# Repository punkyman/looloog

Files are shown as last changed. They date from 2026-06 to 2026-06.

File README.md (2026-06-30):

# looloog

The looloog is a DIY midi instrument intended to make custom inputs for [vcvrack](https://vcvrack.com/)

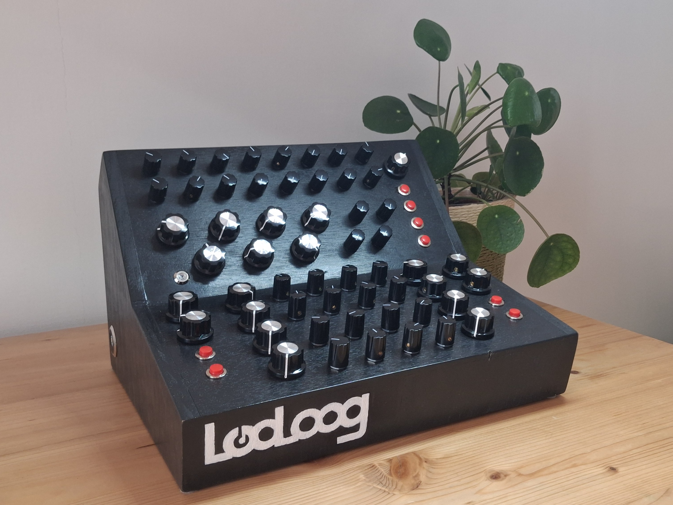
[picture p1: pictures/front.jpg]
Front of the looloog


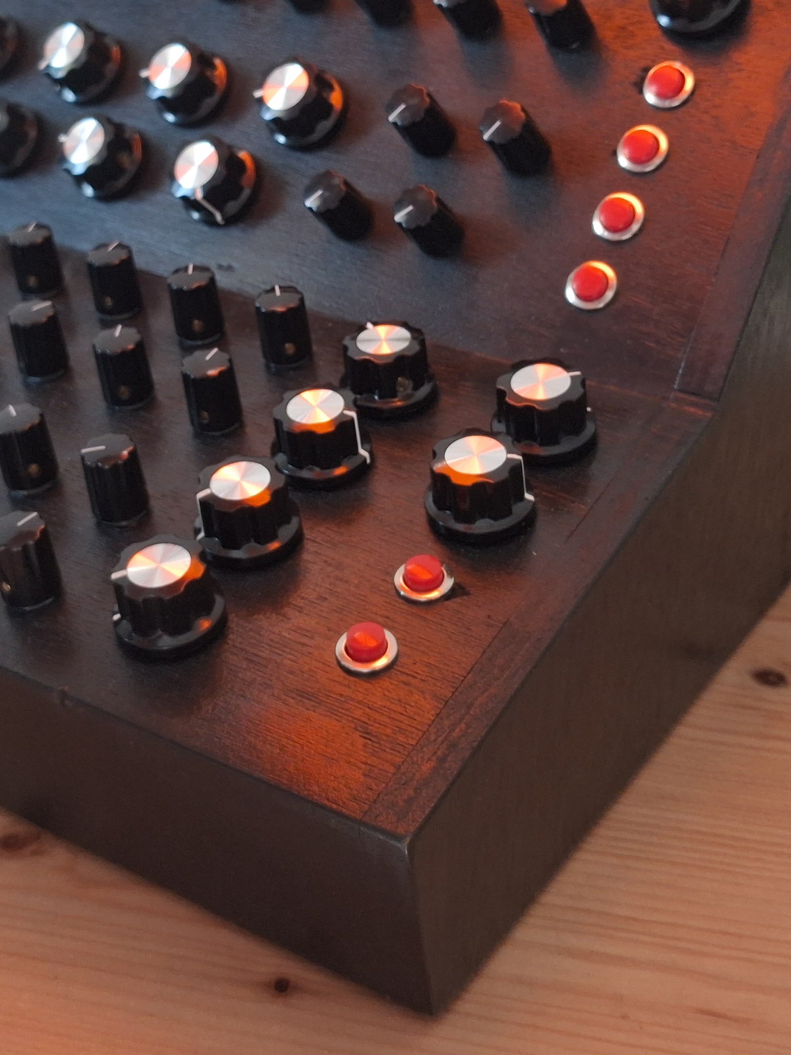
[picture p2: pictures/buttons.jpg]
Buttons of the looloog


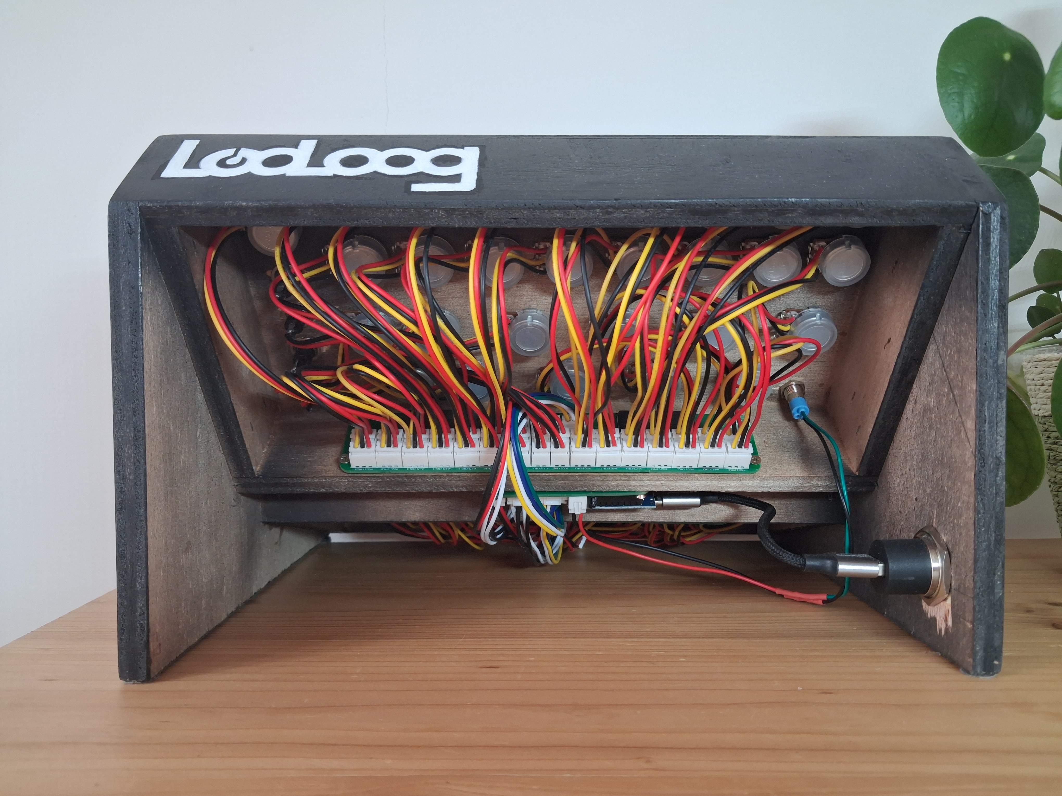
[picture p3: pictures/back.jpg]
Back of the looloog


The case is made out of wood, the electronics is based on arduino, and custom pcb allows for 56 pots and 8 buttons wired simultaneously, all encoded in midi and transmitted through USB. Of course it's a USB type B, it's a controller :)

## Hardware
The hardware is made out of :
- an arduino "pro micro" board; this board is an equivalent of the arduino leonardo board which allows for HID devices and classic arduino programming on the same USB port, all in a condensed package. The version is the 5v/16Mhz version.
- four CD74HC4067 multiplexers; these are 16 inputs multiplexers that allows to connect analog or digital inputs and route them to a single input on the arduino board. The revision used is the E version which was more available than the standard version and has a larger footprint
- Custom PCBs, one for the main board of the arduino, two for the controls on each panel
- 56x 100k linear variable potentiometers (with dust covers)
- 8 push buttons
- 1 white LED to know that the device is plugged in
- a USB type B block for external connectivity, which converts to USB type A, and then to type C through a small USB cable :)

## Prototype

Original prototype was made on a breadboard to validate the minimum hardware and that digital and analog input could be used on the same multiplexer.

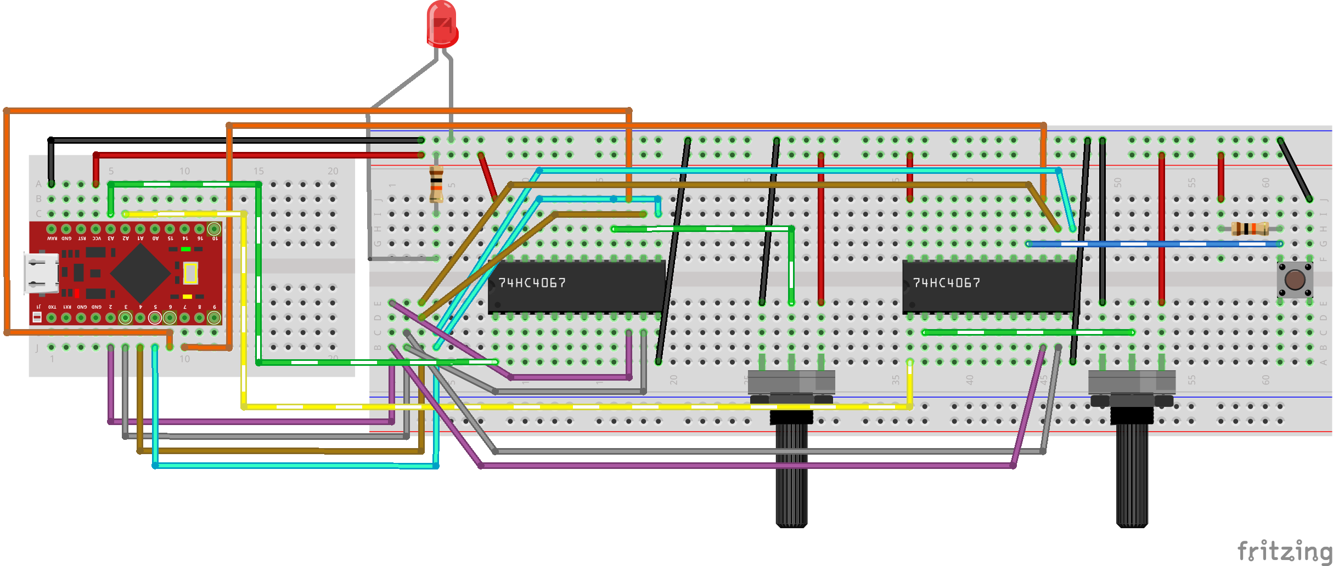
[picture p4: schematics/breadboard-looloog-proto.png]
Breadboard


## PCBs

All PCB designs made with EasyEDA; the choice has been made to handle all the wiring with JST-XH connectors, which looked like a good compromise between connectivity and space used on the PCB.

### Main PCB
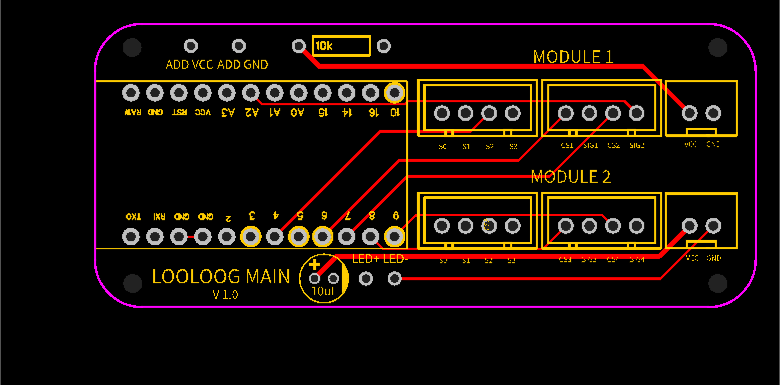
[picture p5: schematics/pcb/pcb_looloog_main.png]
Main PCB


The main PCB holds the arduino board and connects to the two module boards. A small capacitor has been added to the board to handle possible power issues. While designing the PCB, external wires were planned in case the arduino does not provide enough current for the circuit, but this turned out to not be a problem when the full assembly was finished.

Gerber file available here : [Main PCB gerber](schematics/pcb/pcb-looloog-main.zip)

### Module PCB
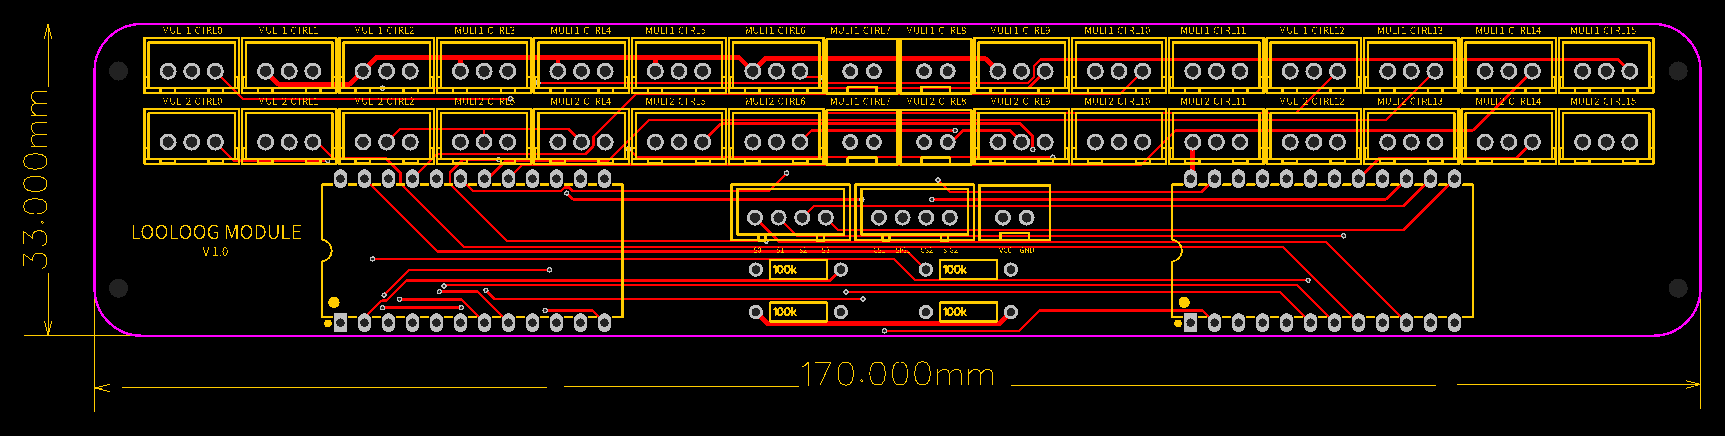
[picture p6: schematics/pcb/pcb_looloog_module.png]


A module PCB holds two multiplexers to handle 28 potentiometers and 4 push buttons. The connectors layout has been lined up so that the inputs can be wired along all the length of the controller. Planning the push buttons in the middle turned out to be a bit short on one of the layouts, this could be improved on other revisions of the PCB design.

Gerber file available here : [Module PCB gerber](schematics/pcb/pcb-looloog-module.zip)

## Code

The project is made for VSCode and PlatformIO, all configured for the pro micro board selected for the project.
The code makes use of an already existing usb midi library which does most of the job in terms of HID device; the only change happens in *configureUSBInfos.py*, where the device reports its name as the "Looloog" :)

There is an option that outputs the commands on serial instead of sending them through USB midi; this is available for debugging purposes and can be enabled by commenting out the line in platformio.ini :
```
;build_flags = -D DEBUG_MIDI_THROUGH_SERIAL
```
All inputs send CC changes through USB midi, being split into 4 midi channels. An improvement could be to create a Module class that would represent one panel with its two multiplexers instead of having 4 multiplexers declared; that would make the instrument have 2 midi channels instead of 4, making things a bit easier on the logic when being used on the computer.

Some of the potentiometers turned out to be jiggling a bit when being used; that is due to the arduino ADC reading the value on 10bit with a precision that was somewhat low, and the code mapping the reading to midi 7bit values. When reading the potentiometer values, there is now a margin that allows measuring little variations before considering a real midi CC change.

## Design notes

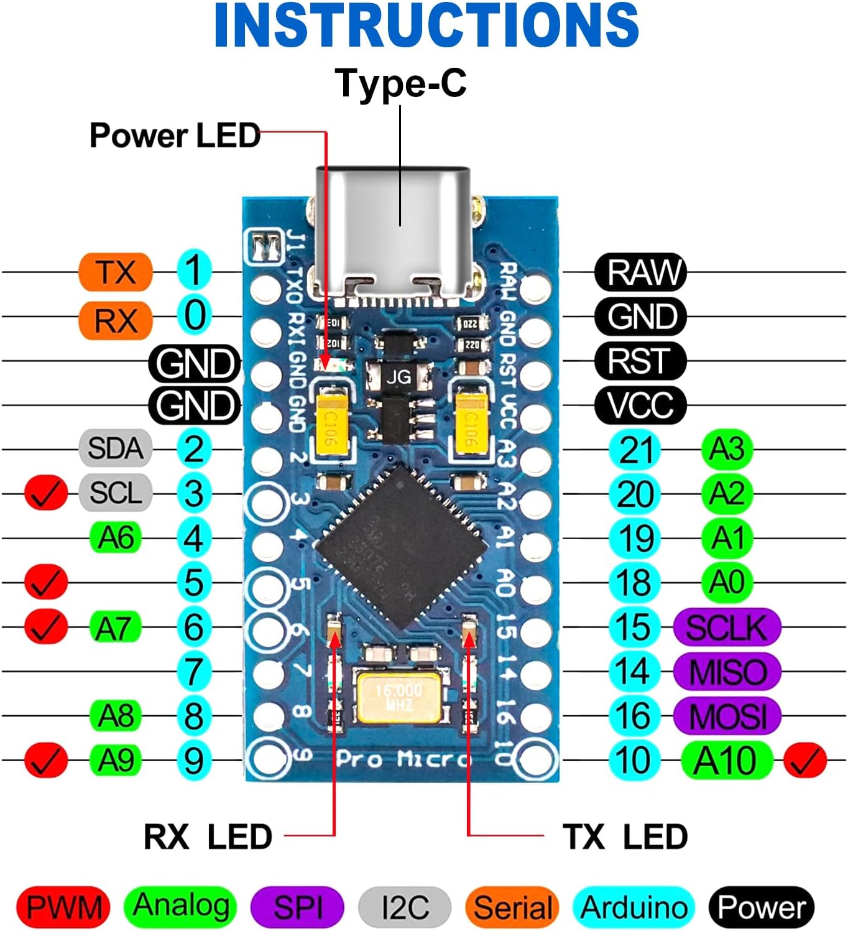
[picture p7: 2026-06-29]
schematics/pro micro layout.jpg

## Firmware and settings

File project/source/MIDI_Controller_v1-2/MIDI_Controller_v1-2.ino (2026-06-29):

#include <MIDI.h>
#include "Controller.h"

/*************************************************************
  MIDI CONTROLLER

  by Notes and Volts
  www.notesandvolts.com

  Version 1.2 **Arduino UNO ONLY!**
 *************************************************************/

MIDI_CREATE_DEFAULT_INSTANCE();

//************************************************************
//***SET THE NUMBER OF CONTROLS USED**************************
//************************************************************
//---How many buttons are connected directly to pins?---------
byte NUMBER_BUTTONS = 0;
//---How many potentiometers are connected directly to pins?--
byte NUMBER_POTS = 0;
//---How many buttons are connected to a multiplexer?---------
byte NUMBER_MUX_BUTTONS = 0;
//---How many potentiometers are connected to a multiplexer?--
byte NUMBER_MUX_POTS = 0;
//************************************************************

//***ANY MULTIPLEXERS? (74HC4067)************************************
//MUX address pins must be connected to Arduino UNO pins 2,3,4,5
//A0 = PIN2, A1 = PIN3, A2 = PIN4, A3 = PIN5
//*******************************************************************
//Mux NAME (OUTPUT PIN, , How Many Mux Pins?(8 or 16) , Is It Analog?);


//Mux M1(10, 16, false); //Digital multiplexer on Arduino pin 10
//Mux M2(A5, 8, true); //Analog multiplexer on Arduino analog pin A0
//*******************************************************************


//***DEFINE DIRECTLY CONNECTED POTENTIOMETERS************************
//Pot (Pin Number, Command, CC Control, Channel Number)
//**Command parameter is for future use**

//Pot PO1(A0, 0, 1, 1);
//Pot PO2(A1, 0, 10, 1);
//Pot PO3(A2, 0, 22, 1);
//Pot PO4(A3, 0, 118, 1);
//Pot PO5(A4, 0, 30, 1);
//Pot PO6(A5, 0, 31, 1);
//*******************************************************************
//Add pots used to array below like this->  Pot *POTS[] {&PO1, &PO2, &PO3, &PO4, &PO5, &PO6};
Pot *POTS[] {};
//*******************************************************************


//***DEFINE DIRECTLY CONNECTED BUTTONS*******************************
//Button (Pin Number, Command, Note Number, Channel, Debounce Time)
//** Command parameter 0=NOTE  1=CC  2=Toggle CC **

//Button BU1(2, 0, 60, 1, 5 );
//Button BU2(3, 0, 61, 1, 5 );
//Button BU3(4, 0, 62, 1, 5 );
//Button BU4(5, 0, 63, 1, 5 );
//Button BU5(6, 0, 64, 1, 5 );
//Button BU6(7, 0, 65, 1, 5 );
//Button BU7(8, 1, 64, 1, 5 );
//Button BU8(9, 2, 64, 1, 5 );
//*******************************************************************
//Add buttons used to array below like this->  Button *BUTTONS[] {&BU1, &BU2, &BU3, &BU4, &BU5, &BU6, &BU7, &BU8};
Button *BUTTONS[] {};
//*******************************************************************


//***DEFINE BUTTONS CONNECTED TO MULTIPLEXER*************************
//Button::Button(Mux mux, byte muxpin, byte command, byte value, byte channel, byte debounce)
//** Command parameter 0=NOTE  1=CC  2=Toggle CC **

//Button MBU1(M1, 0, 0, 70, 1, 5);
//Button MBU2(M1, 1, 1, 71, 1, 5);
//Button MBU3(M1, 2, 2, 72, 1, 5);
//Button MBU4(M1, 3, 0, 73, 1, 5);
//Button MBU5(M1, 4, 0, 74, 1, 5);
//Button MBU6(M1, 5, 0, 75, 1, 5);
//Button MBU7(M1, 6, 0, 76, 1, 5);
//Button MBU8(M1, 7, 0, 77, 1, 5);
//Button MBU9(M1, 8, 0, 78, 1, 5);
//Button MBU10(M1, 9, 0, 79, 1, 5);
//Button MBU11(M1, 10, 0, 80, 1, 5);
//Button MBU12(M1, 11, 0, 81, 1, 5);
//Button MBU13(M1, 12, 0, 82, 1, 5);
//Button MBU14(M1, 13, 0, 83, 1, 5);
//Button MBU15(M1, 14, 0, 84, 1, 5);
//Button MBU16(M1, 15, 0, 85, 1, 5);
//*******************************************************************
////Add multiplexed buttons used to array below like this->  Button *MUXBUTTONS[] {&MBU1, &MBU2, &MBU3, &MBU4, &MBU5, &MBU6.....};
Button *MUXBUTTONS[] {};

//*******************************************************************


//***DEFINE POTENTIOMETERS CONNECTED TO MULTIPLEXER*******************
//Pot::Pot(Mux mux, byte muxpin, byte command, byte control, byte channel)
//**Command parameter is for future use**

//Pot MPO1(M2, 0, 0, 1, 1);
//Pot MPO2(M2, 1, 0, 7, 1);
//Pot MPO3(M2, 2, 0, 50, 1);
//Pot MPO4(M2, 3, 0, 55, 2);
//Pot MPO5(M2, 4, 0, 50, 1);
//Pot MPO6(M2, 5, 0, 55, 2);
//Pot MPO7(M2, 6, 0, 50, 1);
//Pot MPO8(M2, 7, 0, 55, 2);
//Pot MPO9(M2, 8, 0, 50, 1);
//Pot MPO10(M2, 9, 0, 55, 2);
//Pot MPO11(M2, 10, 0, 50, 1);
//Pot MPO12(M2, 11, 0, 55, 2);
//Pot MPO13(M2, 12, 0, 50, 1);
//Pot MPO14(M2, 13, 0, 55, 2);
//Pot MPO15(M2, 14, 0, 50, 1);
//Pot MPO16(M2, 15, 0, 55, 2);
//*******************************************************************
//Add multiplexed pots used to array below like this->  Pot *MUXPOTS[] {&MPO1, &MPO2, &MPO3, &MPO4, &MPO5, &MPO6.....};
Pot *MUXPOTS[] {};
//*******************************************************************


void setup() {
  MIDI.begin(MIDI_CHANNEL_OFF);
}

void loop() {
  if (NUMBER_BUTTONS != 0) updateButtons();
  if (NUMBER_POTS != 0) updatePots();
  if (NUMBER_MUX_BUTTONS != 0) updateMuxButtons();
  if (NUMBER_MUX_POTS != 0) updateMuxPots();
}


//*****************************************************************
void updateButtons() {

  // Cycle through Button array
  for (int i = 0; i < NUMBER_BUTTONS; i = i + 1) {
    byte message = BUTTONS[i]->getValue();

    //  Button is pressed
    if (message == 0) {
      switch (BUTTONS[i]->Bcommand) {
        case 0: //Note
          MIDI.sendNoteOn(BUTTONS[i]->Bvalue, 127, BUTTONS[i]->Bchannel);
          break;
        case 1: //CC
          MIDI.sendControlChange(BUTTONS[i]->Bvalue, 127, BUTTONS[i]->Bchannel);
          break;
        case 2: //Toggle
          if (BUTTONS[i]->Btoggle == 0) {
            MIDI.sendControlChange(BUTTONS[i]->Bvalue, 127, BUTTONS[i]->Bchannel);
            BUTTONS[i]->Btoggle = 1;
          }
          else if (BUTTONS[i]->Btoggle == 1) {
            MIDI.sendControlChange(BUTTONS[i]->Bvalue, 0, BUTTONS[i]->Bchannel);
            BUTTONS[i]->Btoggle = 0;
          }
          break;
      }
    }

    //  Button is not pressed
    if (message == 1) {
      switch (BUTTONS[i]->Bcommand) {
        case 0:
          MIDI.sendNoteOff(BUTTONS[i]->Bvalue, 0, BUTTONS[i]->Bchannel);
          break;
        case 1:
          MIDI.sendControlChange(BUTTONS[i]->Bvalue, 0, BUTTONS[i]->Bchannel);
          break;
      }
    }
  }
}
//*******************************************************************
void updateMuxButtons() {

  // Cycle through Mux Button array
  for (int i = 0; i < NUMBER_MUX_BUTTONS; i = i + 1) {

    MUXBUTTONS[i]->muxUpdate();
    byte message = MUXBUTTONS[i]->getValue();

    //  Button is pressed
    if (message == 0) {
      switch (MUXBUTTONS[i]->Bcommand) {
        case 0: //Note
          MIDI.sendNoteOn(MUXBUTTONS[i]->Bvalue, 127, MUXBUTTONS[i]->Bchannel);
          break;
        case 1: //CC
          MIDI.sendControlChange(MUXBUTTONS[i]->Bvalue, 127, MUXBUTTONS[i]->Bchannel);
          break;
        case 2: //Toggle
          if (MUXBUTTONS[i]->Btoggle == 0) {
            MIDI.sendControlChange(MUXBUTTONS[i]->Bvalue, 127, MUXBUTTONS[i]->Bchannel);
            MUXBUTTONS[i]->Btoggle = 1;
          }
          else if (MUXBUTTONS[i]->Btoggle == 1) {
            MIDI.sendControlChange(MUXBUTTONS[i]->Bvalue, 0, MUXBUTTONS[i]->Bchannel);
            MUXBUTTONS[i]->Btoggle = 0;
          }
          break;
      }
    }
    //  Button is not pressed
    if (message == 1) {
      switch (MUXBUTTONS[i]->Bcommand) {
        case 0:
          MIDI.sendNoteOff(MUXBUTTONS[i]->Bvalue, 0, MUXBUTTONS[i]->Bchannel);
          break;
        case 1:
          MIDI.sendControlChange(MUXBUTTONS[i]->Bvalue, 0, MUXBUTTONS[i]->Bchannel);
          break;
      }
    }
  }
}
//***********************************************************************
void updatePots() {
  for (int i = 0; i < NUMBER_POTS; i = i + 1) {
    byte potmessage = POTS[i]->getValue();
    if (potmessage != 255) MIDI.sendControlChange(POTS[i]->Pcontrol, potmessage, POTS[i]->Pchannel);
  }
}
//***********************************************************************
void updateMuxPots() {
  for (int i = 0; i < NUMBER_MUX_POTS; i = i + 1) {
    MUXPOTS[i]->muxUpdate();
    byte potmessage = MUXPOTS[i]->getValue();
    if (potmessage != 255) MIDI.sendControlChange(MUXPOTS[i]->Pcontrol, potmessage, MUXPOTS[i]->Pchannel);
  }
}

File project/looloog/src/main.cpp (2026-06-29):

#include <Arduino.h>
#include "board_utils.h"

#define D6 6
#define D7 7
#define D8 8
#define D9 9

#define BUS_S0_PIN 2
#define BUS_S1_PIN 3
#define BUS_S2_PIN 4
#define BUS_S3_PIN 5

#define MODULE_1_MUX_1_MIDI_CHANNEL 1
#define MODULE_1_MUX_2_MIDI_CHANNEL 2
#define MODULE_2_MUX_1_MIDI_CHANNEL 3
#define MODULE_2_MUX_2_MIDI_CHANNEL 4

DECLARE_MUX(g_module1Mux1, D6, A3, MODULE_1_MUX_1_MIDI_CHANNEL)
DECLARE_MUX(g_module1Mux2, D7, A2, MODULE_1_MUX_2_MIDI_CHANNEL)
DECLARE_MUX(g_module2Mux1, D8, A1, MODULE_2_MUX_1_MIDI_CHANNEL)
DECLARE_MUX(g_module2Mux2, D9, A0, MODULE_2_MUX_2_MIDI_CHANNEL)

void setup() {
  Serial.begin(9600);

  // initialize bus shared by all mux
  Mux::InitMuxBus(BUS_S0_PIN, BUS_S1_PIN, BUS_S2_PIN, BUS_S3_PIN);
}

void loop() {
  unsigned long start = millis();

  g_module1Mux1.Update();
  g_module1Mux2.Update();

  g_module2Mux1.Update();
  g_module2Mux2.Update();

  unsigned long duration = millis() - start;
  // cap refresh rate to 60hz
  delay(16 - duration);
}

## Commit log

2026-03-15 add multiplexers schematics
2026-03-15 add sample source code for midi controller
2026-03-15 add fritzing breadboard scheme
    [breadboard-looloog-proto.fzz]
2026-03-20 switch to a higher level midi library
2026-03-20 first throw of the implementation for pot and button
2026-03-21 fix logic error in mux output
    [mux.cpp]
2026-03-21 first throw of the main, does not work for now
    [main.cpp]
2026-03-21 implement cable select
2026-03-21 update schematic following error on bus pins
    [breadboard-looloog-proto.fzz]
2026-03-21 picky change on pin naming
2026-03-21 fix error on for loop
    [mux.cpp]
2026-03-21 fix button initial value
2026-03-31 fix error on pointers and allocation
    [main.cpp, mux.cpp]
2026-03-31 fix serial prints
2026-03-31 fix s0/s3 order, simplify update loop
    [mux.cpp]
2026-04-01 add safety on input pin
2026-04-01 rewrite print lns
2026-04-01 main sample with a pot and a button
2026-04-02 switch serialmidi to usbmidi
2026-04-03 remove lib dependency since switch to usb
2026-04-03 add platformio configuration to modify usb name reported by device
2026-04-03 fix error on bus pins of ICs
    [breadboard-looloog-proto.fzz]
2026-04-03 update polarity on pots to fix value reading issues
    [breadboard-looloog-proto.fzz]
2026-04-04 add led to circuit to indicate that the instrument is on
    [breadboard-looloog-proto.fzz]
2026-04-09 rewrite main to match pcb structure and layout
2026-04-19 fix ground wire error
    [breadboard-looloog-proto.fzz]
2026-06-02 implement a jitter margin to compensate for DAC measurements precision
2026-06-29 add gerber files
2026-06-30 add png of circuits
